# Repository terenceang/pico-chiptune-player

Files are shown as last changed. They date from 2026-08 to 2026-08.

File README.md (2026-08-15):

# Pico Chiptune Player

**Version:** 0.4 (Manufactured Production Release)  
**Author:** Terence Ang <terenceang@mac.com>  
**Company:** MotionFxDesign  
**License:** [CC BY-NC-SA 4.0](LICENSE) (Creative Commons Attribution-NonCommercial-ShareAlike 4.0 International) — **NOT FOR COMMERCIAL USE**  

---

## Overview

The **Pico Chiptune Player** is an open-hardware music player powered by the **Raspberry Pi Pico 2 (RP2350)** microcontroller driving an authentic **General Instrument AY-3-8910** (or **Yamaha YM2149F**) 3-voice Programmable Sound Generator (PSG).

It enables standalone playback of classic AY-3-8910 / YM2149 chiptune music formats (e.g., `.ym`, `.vgm`, `.psg`, `.pt3`) loaded directly from an onboard microSD card, with song and playback metadata displayed on an I2C OLED display.

---

## Hardware Highlights

- **Microcontroller:** Raspberry Pi Pico 2 (RP2350)
- **Sound Generator:** General Instrument AY-3-8910 / Yamaha YM2149F (40-pin DIP)
- **Audio Output:**
  - 3-channel passive summing mixer (`R4`, `R5`, `R7`, `R8` = 1kΩ)
  - Anti-aliasing / low-pass filter capacitor (`C4` = 100nF)
  - AC coupling capacitor (`C3` = 1µF)
  - Onboard Adafruit PAM8302A 2.5W Mono Class-D Audio Amplifier Module (`U3`) with hardware GPIO mute/shutdown control (`SD_Amp` on GPIO9)
  - Direct differential speaker terminals (`OUT+`, `OUT-`)
- **Display:** 0.96" SSD1306 128x64 I2C OLED Display (`U2`)
- **Storage:** MicroSD Card Slot via SPI mode with Card Detect (`J2`)
- **Controls:** 3 tactile pushbuttons (`SW1` Play/Pause, `SW2` Next Track, `SW3` Previous Track)
- **Clock Divider Select:** Solder jumper `JP1` for YM2149 ÷2 internal clock divider selection

---

## Pinout Summary (Raspberry Pi Pico 2)

| GPIO | Pico Pin | Net / Signal | Connected Subsystem |
| :--- | :--- | :--- | :--- |
| **`GPIO0..GPIO7`** | Pins 1, 2, 4..7, 9, 10 | `DA0..DA7` | AY-3-8910 8-Bit Data Bus (Pins 37..30) |
| **`GPIO8`** | Pin 11 | `BC1` | AY-3-8910 Bus Control 1 (Pin 29) |
| **`GPIO9`** | Pin 12 | `SD_Amp` | PAM8302 Audio Amp Shutdown / Mute Control (`U3` Pin 3) |
| **`GPIO10`** | Pin 14 | `BDIR` | AY-3-8910 Bus Direction Control (Pin 27) |
| **`GPIO11`** | Pin 15 | `~RESET` | AY-3-8910 Active-Low Reset (Pin 23) + 10kΩ R3 Pull-down |
| **`GPIO12`** | Pin 16 | `CLOCK` | AY-3-8910 Master Clock Input (Pin 22 via 33Ω series R2) |
| **`GPIO13`** | Pin 17 | `SW_NEXT` | Next Track Button (`SW2`) |
| **`GPIO14`** | Pin 19 | `SW_PLAY` | Play / Pause Button (`SW1`) |
| **`GPIO15`** | Pin 20 | `SW_PREV` | Previous Track Button (`SW3`) |
| **`GPIO16`** | Pin 21 | `OLED_SCL` | 0.96" OLED I2C SCL (`U2` Pin 3) |
| **`GPIO17`** | Pin 22 | `OLED_SDA` | 0.96" OLED I2C SDA (`U2` Pin 4) |
| **`GPIO18`** | Pin 24 | `SD_CS` | MicroSD SPI Chip Select (`J2` Pin 2 + 10kΩ R1 Pull-up) |
| **`GPIO19`** | Pin 25 | `SD_MOSI` | MicroSD SPI Data Input (`J2` Pin 3) |
| **`GPIO20`** | Pin 26 | `SD_SCK` | MicroSD SPI Clock (`J2` Pin 5) |
| **`GPIO21`** | Pin 27 | `SD_MISO` | MicroSD SPI Data Output (`J2` Pin 7) |
| **`GPIO22`** | Pin 29 | `SD_Card_Detect` | MicroSD Card Detect Switch (`J2` Pin 9) |

For the complete hardware design details, circuit topology, and full Bill of Materials with LCSC part numbers, refer to [HARDWARE.md](HARDWARE.md).

---

## License & Commercial Use Notice

Copyright (c) 2026 Terence Ang <terenceang@mac.com> / MotionFxDesign.

This project is licensed under the **Creative Commons Attribution-NonCommercial-ShareAlike 4.0 International License (CC BY-NC-SA 4.0)**.

> **NOT FOR COMMERCIAL USE**  
> This design, including schematics, PCB layouts, Gerber files, firmware, and documentation, is free for personal, hobby, educational, and non-commercial use.  
> **Commercial manufacture, distribution, sale, or bundling for profit is strictly prohibited** without prior written authorization from Terence Ang (<terenceang@mac.com>).

See the [LICENSE](LICENSE) file for the complete license terms.

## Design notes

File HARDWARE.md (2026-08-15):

# Hardware Documentation - Pico Chiptune Player

**Title:** Pico Chiptune Player  
**Author:** Terence Ang <terenceang@mac.com> / MotionFxDesign  
**Company:** MotionFxDesign  
**Status:** Manufactured / Sent to Production (Schematic SSOT)  
**Version / Rev:** 0.4  
**Date:** 2026-08-15  
**License:** Creative Commons Attribution-NonCommercial-ShareAlike 4.0 International (CC BY-NC-SA 4.0) — NOT FOR COMMERCIAL USE  

---

## 1. Overview

The **Pico Chiptune Player** is a dedicated hardware chiptune music player powered by a **Raspberry Pi Pico 2 (RP2350)** microcontroller driving a real **General Instrument AY-3-8910** (or **Yamaha YM2149F**) 3-voice Programmable Sound Generator (PSG).

### Key Features & Subsystems
- **Microcontroller:** Raspberry Pi Pico 2 (RP2350) microcontroller running the chiptune player firmware, file parser, and UI.
- **Sound Generator:** AY-3-8910 / YM2149F 40-pin DIP PSG interfaced via an 8-bit parallel bus (`DA0..DA7`), bus control lines (`BC1`, `BDIR`), active-low reset (`~RESET`), and a hardware master clock output with series damping.
- **Audio Summer & Filter:** 3-channel passive resistive summing network (`R4`, `R5`, `R7` = 1kΩ, `R8` = 1kΩ load) with high-cut low-pass filtering (`C4` = 100nF) and AC output coupling (`C3` = 1µF).
- **Audio Amplifier:** Onboard **Adafruit PAM8302A 2.5W Mono Class-D Audio Amplifier Module** (`U3`) header with hardware GPIO shutdown/mute control (`SD_Amp`).
- **Speaker Output:** Direct differential `OUT+` / `OUT-` speaker terminals on the PAM8302 module breakout.
- **Display:** 0.96" 128x64 I2C OLED display module (`U2`) with bulk and high-frequency decoupling (`C6` = 10µF, `C7` = 100nF).
- **Storage:** Full SPI microSD card socket (`J2`) with hardware card detect (`SD_Card_Detect`) and dedicated pull-up (`R1` = 10kΩ).
- **Navigation Controls:** 3 tactile pushbuttons (`SW1` Play/Pause, `SW2` Next Track, `SW3` Previous Track).
- **Clock Divider Select:** Solder jumper `JP1` to select YM2149 internal ÷2 clock division.

---

## 2. Block Diagram

```
                             +-------------------+
                             |  Raspberry Pi     |
                             | Pico 2 (RP2350)   |
                             +--+---+---+---+----+
                                |   |   |   |
          +---------------------+   |   |   +-----------------------+
          | (SPI: GPIO18..22)       |   | (I2C: GPIO16, 17)         | (GPIO13, 14, 15)
          v                         v   v                           v
+------------------+         +------------+                    +-----------+
| microSD Card     |         | 0.96" OLED |                    | Buttons   |
| Slot (J2)        |         | Display(U2)|                    | (SW1..3)  |
+------------------+         +------------+                    +-----------+
                                    |
            +-----------------------+
            | 8-Bit Parallel Data Bus: DA0..DA7 (GPIO0..7)
            | Bus Control: BC1 (GPIO8), BDIR (GPIO10)
            | Active-Low Reset: ~RESET (GPIO11) + 10kΩ R3 Pull-down
            | Master Clock: CLOCK (GPIO12) + 33Ω R2 Series Damping
            | Amp Shutdown Control: SD_Amp (GPIO9)
            v
  +--------------------+
  | AY-3-8910 / YM2149 | <--- JP1 (YM2149 /SEL ÷2 Clock Mode Jumper)
  +---------+----------+
            |
            | ANALOG_A, ANALOG_B, ANALOG_C
            v
  +--------------------+
  | Passive Mono Mixer | (R4=1k, R5=1k, R7=1k Summing + R8=1k Load + C4=100nF LPF)
  +---------+----------+
            |
            v
  +--------------------+
  | AC Output Coupling | (C3 = 1µF Polarized Electrolytic Cap)
  +---------+----------+
            |
            | Net-(U3-A+)
            v
  +--------------------+
  | Mono Audio Amp     | (U3: Adafruit PAM8302A 2.5W Class-D Module)
  | Breakout Header    | (VIN=+5V with C8=100nF, A-=GND, SD=GPIO9 SD_Amp)
  +---------+----------+
            |
            v
     Differential Speaker Terminals (OUT+ / OUT- on U3)
```

---

## 3. Complete Pinout & Wiring Tables (SSOT)

### 3.1 Raspberry Pi Pico 2 (A1) Pin Connections

| Pico Pin | Pin Name / GPIO | Net Name | Connected To | Signal Description |
| :--- | :--- | :--- | :--- | :--- |
| **Pin 1** | **GPIO0** | `DA0` | AY-3-8910 (U1) Pin 37 | PSG 8-Bit Data Bus Bit 0 |
| **Pin 2** | **GPIO1** | `DA1` | AY-3-8910 (U1) Pin 36 | PSG 8-Bit Data Bus Bit 1 |
| **Pin 3** | **GND** | `GND` | Ground Plane | System Ground |
| **Pin 4** | **GPIO2** | `DA2` | AY-3-8910 (U1) Pin 35 | PSG 8-Bit Data Bus Bit 2 |
| **Pin 5** | **GPIO3** | `DA3` | AY-3-8910 (U1) Pin 34 | PSG 8-Bit Data Bus Bit 3 |
| **Pin 6** | **GPIO4** | `DA4` | AY-3-8910 (U1) Pin 33 | PSG 8-Bit Data Bus Bit 4 |
| **Pin 7** | **GPIO5** | `DA5` | AY-3-8910 (U1) Pin 32 | PSG 8-Bit Data Bus Bit 5 |
| **Pin 8** | **GND** | `GND` | Ground Plane | System Ground |
| **Pin 9** | **GPIO6** | `DA6` | AY-3-8910 (U1) Pin 31 | PSG 8-Bit Data Bus Bit 6 |
| **Pin 10** | **GPIO7** | `DA7` | AY-3-8910 (U1) Pin 30 | PSG 8-Bit Data Bus Bit 7 |
| **Pin 11** | **GPIO8** | `BC1` | AY-3-8910 (U1) Pin 29 | Bus Control 1 (Address Latch / Data Write) |
| **Pin 12** | **GPIO9** | `SD_Amp` | PAM8302 Module (U3) Pin 3 | Audio Amplifier Shutdown Control (Active High Enable / Low Mute) |
| **Pin 13** | **GND** | `GND` | Ground Plane | System Ground |
| **Pin 14** | **GPIO10** | `BDIR` | AY-3-8910 (U1) Pin 27 | Bus Direction Control |
| **Pin 15** | **GPIO11** | `~RESET` | AY-3-8910 (U1) Pin 23, R3 | PSG Active-Low Reset (with 10kΩ pull-down R3 to GND) |
| **Pin 16** | **GPIO12** | `Net-(A1-GPIO12)` | Resistor R2 Pin 2 (33Ω) | PSG Master Clock Output (series damped to U1 Pin 22 `CLOCK`) |
| **Pin 17** | **GPIO13** | `SW_NEXT` | Tact Switch SW2 Pin 1 | Next Track Button (Active Low, Internal Pull-up) |
| **Pin 18** | **GND** | `GND` | Ground Plane | System Ground |
| **Pin 19** | **GPIO14** | `SW_PLAY` | Tact Switch SW1 Pin 1 | Play / Pause Button (Active Low, Internal Pull-up) |
| **Pin 20** | **GPIO15** | `SW_PREV` | Tact Switch SW3 Pin 1 | Previous Track Button (Active Low, Internal Pull-up) |
| **Pin 21** | **GPIO16** | `OLED_SCL` | OLED Display (U2) Pin 3 | I2C Serial Clock (SCL, Internal / Display Pull-up) |
| **Pin 22** | **GPIO17** | `OLED_SDA` | OLED Display (U2) Pin 4 | I2C Serial Data (SDA, Internal / Display Pull-up) |
| **Pin 23** | **GND** | `GND` | Ground Plane | System Ground |
| **Pin 24** | **GPIO18** | `SD_CS` | MicroSD (J2) Pin 2, R1 | SPI Chip Select (CS, with 10kΩ pull-up R1 to +3.3V) |
| **Pin 25** | **GPIO19** | `SD_MOSI` | MicroSD (J2) Pin 3 | SPI Master Out Slave In (CMD / DI) |
| **Pin 26** | **GPIO20** | `SD_SCK` | MicroSD (J2) Pin 5 | SPI Serial Clock (CLK) |
| **Pin 27** | **GPIO21** | `SD_MISO` | MicroSD (J2) Pin 7 | SPI Master In Slave Out (DAT0 / DO) |
| **Pin 28** | **GND** | `GND` | Ground Plane | System Ground |
| **Pin 29** | **GPIO22** | `SD_Card_Detect` | MicroSD (J2) Pin 9 | MicroSD Card Detect (Active Low to GND when inserted) |
| **Pin 30** | **RUN** | `N/C` | — | Reset input (Unconnected) |
| **Pin 31** | **GPIO26_ADC0** | `N/C` | — | Analog input 0 (Unconnected) |
| **Pin 32** | **GPIO27_ADC1** | `N/C` | — | Analog input 1 (Unconnected) |
| **Pin 33** | **AGND** | `N/C` | — | Analog ground (Unconnected) |
| **Pin 34** | **GPIO28_ADC2** | `N/C` | — | Analog input 2 (Unconnected) |
| **Pin 35** | **ADC_VREF** | `N/C` | — | ADC reference (Unconnected) |
| **Pin 36** | **3V3** | `+3.3V` | MicroSD J2, OLED U2, R1, C5..C7 | 3.3V System Power Rail (Sourced from Pico onboard regulator) |
| **Pin 37** | **3V3_EN** | `N/C` | — | 3.3V regulator enable (Unconnected) |
| **Pin 38** | **GND** | `GND` | Ground Plane | System Ground |
| **Pin 39** | **VSYS** | `N/C` | — | System supply input (Unconnected) |
| **Pin 40** | **VBUS** | `+5V` | U1 Pin 40/25/28, U3 Pin 2, C1, C2, C8 | 5V Main Power Rail (Sourced from Pico USB VBUS) |

---

### 3.2 AY-3-8910 / YM2149 Sound Generator (U1) Pinout

| Pin | Symbol | Net Name | Connected To | Notes / Function |
| :--- | :--- | :--- | :--- | :--- |
| **1** | `VSS` | `GND` | Ground Plane | Power Ground |
| **2** | `NC` | `NC` | Unconnected | No Connect |
| **3** | `ANALOG_B` | `ANALOG_B` | Resistor R5 (1kΩ) | Channel B Analog Audio Output |
| **4** | `ANALOG_A` | `ANALOG_A` | Resistor R4 (1kΩ) | Channel A Analog Audio Output |
| **5** | `NC` | `NC` | Unconnected | No Connect |
| **6..13** | `IOB7..IOB0` | `NC` | Unconnected | General Purpose I/O Port B (Unused) |
| **14..21**| `IOA7..IOA0` | `NC` | Unconnected | General Purpose I/O Port A (Unused) |
| **22** | `CLOCK` | `CLOCK` | Resistor R2 Pin 1 (33Ω) | Master Clock Input (Driven from Pico GPIO12 via 33Ω series R2) |
| **23** | `~RESET` | `~RESET` | Pico GPIO11, R3 (10kΩ to GND) | Active-Low Hardware Reset (Boot pull-down holds PSG in reset) |
| **24** | `A9` | `GND` | Ground Plane | Fixed Address Decoding Bit 9 (Tied to GND = 0) |
| **25** | `A8` | `+5V` | +5V Rail | Fixed Address Decoding Bit 8 (Tied to +5V = 1) |
| **26** | `~{CS/Test_2}` | `NET-(JP1-A)` | Solder Jumper JP1 Pin 1 | YM2149 Clock Select (/SEL): Open = 1x Clock; Bridged to GND = ÷2 Clock |
| **27** | `BDIR` | `BDIR` | Pico GPIO10 | Bus Direction Control Line |
| **28** | `BC2` | `+5V` | +5V Rail | Bus Control 2 (Tied permanently HIGH to +5V) |
| **29** | `BC1` | `BC1` | Pico GPIO8 | Bus Control 1 Line |
| **30** | `DA7` | `DA7` | Pico GPIO7 | 8-Bit Bidirectional Data Bus Bit 7 |
| **31** | `DA6` | `DA6` | Pico GPIO6 | 8-Bit Bidirectional Data Bus Bit 6 |
| **32** | `DA5` | `DA5` | Pico GPIO5 | 8-Bit Bidirectional Data Bus Bit 5 |
| **33** | `DA4` | `DA4` | Pico GPIO4 | 8-Bit Bidirectional Data Bus Bit 4 |
| **34** | `DA3` | `DA3` | Pico GPIO3 | 8-Bit Bidirectional Data Bus Bit 3 |
| **35** | `DA2` | `DA2` | Pico GPIO2 | 8-Bit Bidirectional Data Bus Bit 2 |
| **36** | `DA1` | `DA1` | Pico GPIO1 | 8-Bit Bidirectional Data Bus Bit 1 |
| **37** | `DA0` | `DA0` | Pico GPIO0 | 8-Bit Bidirectional Data Bus Bit 0 |
| **38** | `ANALOG_C` | `ANALOG_C` | Resistor R7 (1kΩ) | Channel C Analog Audio Output |
| **39** | `TEST1` | `NC` | Unconnected | Test pin (Unconnected) |
| **40** | `VCC` | `+5V` | +5V Rail | Main +5V Power Supply (Decoupled by C1 10µF bulk + C2 100nF MLCC) |

#### AY-3-8910 Bus State Decoding Table (`BC2` Tied HIGH to +5V)

| `BDIR` (GPIO10) | `BC1` (GPIO8) | Bus State | Operation Description |
| :---: | :---: | :--- | :--- |
| **0** | **0** | **INACTIVE** | PSG data bus is High-Z / Inactive. |
| **0** | **1** | **READ** | Pico reads register contents from PSG data bus `DA[7:0]`. |
| **1** | **0** | **WRITE** | Pico writes data on `DA[7:0]` into currently addressed register. |
| **1** | **1** | **LATCH ADDRESS** | Pico selects target PSG register address (0x00..0x0F) on `DA[7:0]`. |

---

### 3.3 MicroSD Card Socket (J2) Pinout

| Pin | Card Signal | Net Name | Connected To | Description |
| :--- | :--- | :--- | :--- | :--- |
| **1** | `DAT2` | `NC` | Unconnected | Unused in SPI Mode |
| **2** | `DAT3 / CD` | `SD_CS` | Pico GPIO18 (Pin 24), R1 | SPI Chip Select (CS) with 10kΩ pull-up R1 to +3.3V |
| **3** | `CMD` | `SD_MOSI` | Pico GPIO19 (Pin 25) | SPI Data Input (DI / MOSI) |
| **4** | `VDD` | `+3.3V` | +3.3V Rail | +3.3V Power Supply (Decoupled by C5 100nF MLCC) |
| **5** | `CLK` | `SD_SCK` | Pico GPIO20 (Pin 26) | SPI Serial Clock (SCK) |
| **6** | `VSS` | `GND` | Ground Plane | Power Ground |
| **7** | `DAT0` | `SD_MISO` | Pico GPIO21 (Pin 27) | SPI Data Output (DO / MISO) |
| **8** | `DAT1` | `NC` | Unconnected | Unused in SPI Mode |
| **9** | `Card Detect`| `SD_Card_Detect`| Pico GPIO22 (Pin 29) | Card Detect Switch (Shorts to GND when card is inserted) |
| **10** | `Casing` | `GND` | Ground Plane | Metal Shield / Housing Ground |

---

### 3.4 Peripherals: OLED (U2), Audio Amp Module (U3), Buttons (SW1..SW3), Jumper (JP1)

| Designator | Pin / Signal | Net Name | Connected To | Description |
| :--- | :--- | :--- | :--- | :--- |
| **`U2` Pin 1** | `VCC` | `+3.3V` | +3.3V Rail | Display Power (Decoupled by C6 10µF + C7 100nF) |
| **`U2` Pin 2** | `GND` | `GND` | Ground Plane | Display Power Ground |
| **`U2` Pin 3** | `SCL` | `OLED_SCL` | Pico GPIO16 (Pin 21) | I2C Serial Clock Line |
| **`U2` Pin 4** | `SDA` | `OLED_SDA` | Pico GPIO17 (Pin 22) | I2C Serial Data Line |
| **`U3` Pin 1** | `GND` | `GND` | Ground Plane | PAM8302 Power Ground |
| **`U3` Pin 2** | `VIN` | `+5V` | +5V Rail | PAM8302 Power Input (Decoupled by C8 100nF) |
| **`U3` Pin 3** | `SD` | `SD_Amp` | Pico GPIO9 (Pin 12) | Hardware Mute / Shutdown (HIGH = Enable, LOW = Mute) |
| **`U3` Pin 4** | `A-` | `GND` | Ground Plane | Differential Audio Negative Reference Input |
| **`U3` Pin 5** | `A+` | `NET-(U3-A+)` | C3 Pin 2 (Negative lead) | AC-Coupled Audio Input from Mixer Summing Junction |
| **`U3` Pin 6** | `OUT+` | `Net-(U3-OUT+-Pad6)` | Breakout Output Terminal | Positive Differential Class-D Speaker Output |
| **`U3` Pin 7** | `OUT-` | `Net-(U3-OUT--Pad7)` | Breakout Output Terminal | Negative Differential Class-D Speaker Output |
| **`SW1` Pin 1** | `1` | `SW_PLAY` | Pico GPIO14 (Pin 19) | Play / Pause Navigation Button (Internal Pull-Up) |
| **`SW1` Pin 2** | `2` | `GND` | Ground Plane | Ground Return |
| **`SW2` Pin 1** | `1` | `SW_NEXT` | Pico GPIO13 (Pin 17) | Next Track Navigation Button (Internal Pull-Up) |
| **`SW2` Pin 2** | `2` | `GND` | Ground Plane | Ground Return |
| **`SW3` Pin 1** | `1` | `SW_PREV` | Pico GPIO15 (Pin 20) | Previous Track Navigation Button (Internal Pull-Up) |
| **`SW3` Pin 2** | `2` | `GND` | Ground Plane | Ground Return |
| **`JP1` Pin 1** | `A` | `NET-(JP1-A)` | AY-3-8910 (U1) Pin 26 | YM2149 /SEL Clock Divider Select Pin |
| **`JP1` Pin 2** | `B` | `GND` | Ground Plane | Ground Return (Bridge pads to enable ÷2 divider) |

---

### 3.5 Passive Audio Mixer & Filtering Topology

The analog audio outputs from the PSG are combined using a low-noise passive summing junction:

1. **Summing Resistors:**
   - Channel A (U1 Pin 4): `R4` (1kΩ, 0805)
   - Channel B (U1 Pin 3): `R5` (1kΩ, 0805)
   - Channel C (U1 Pin 38): `R7` (1kΩ, 0805)
2. **Summing Node (`Net-(C3-Pad1)`):**
   - **Mixer Load Resistor:** `R8` (1kΩ, 0805) to `GND`. Establishes the passive attenuator baseline impedance and DC ground reference.
   - **Low-Pass Filter Capacitor:** `C4` (100nF, 0805 MLCC) to `GND`. Forms a first-order low-pass filter with the equivalent summing impedance ($R_{eq} \approx 250\,\Omega$, cutoff frequency $f_c \approx 6.3\,\text{kHz}$) to eliminate high-frequency digital clock harmonics and PSG switching noise.
   - **AC Output Coupling Capacitor:** `C3` (1µF, 3x5.4mm Electrolytic). Blocks DC bias from the PSG output pins and passes the audio signal into the PAM8302 `A+` differential audio input (`U3` Pin 5).

---

## 4. Bill of Materials & LCSC Part Mapping (SSOT)

| Designator | Value / Part | Package / Footprint | Quantity | LCSC Part # | Description |
| :--- | :--- | :--- | :---: | :--- | :--- |
| **`A1`** | `RaspberryPi_Pico 2` | `TMCu Module:RPi_Pico_SMD_TH` | 1 | — | Raspberry Pi Pico 2 (RP2350) Microcontroller Module |
| **`C1`** | `10uF` | `Capacitor_SMD:CP_Elec_4x5.4` | 1 | `C3343` | Aluminum Electrolytic Bulk Power Decoupling Cap (U1 +5V) |
| **`C2`** | `100nF` | `Capacitor_SMD:C_0805` | 1 | `C1711` | MLCC 0805 High-Frequency Decoupling Cap (U1 +5V) |
| **`C3`** | `1uF` | `Capacitor_SMD:CP_Elec_3x5.4` | 1 | `C3348` | Aluminum Electrolytic Audio Input AC Coupling Cap |
| **`C4`** | `100nF` | `Capacitor_SMD:C_0805` | 1 | `C1710` | MLCC 0805 Audio Mixer Low-Pass Filter Cap |
| **`C5`** | `100nF` | `Capacitor_SMD:C_0805` | 1 | `C1710` | MLCC 0805 MicroSD +3.3V Decoupling Cap |
| **`C6`** | `10uF` | `Capacitor_SMD:CP_Elec_4x5.4` | 1 | `C3343` | Aluminum Electrolytic Bulk Power Decoupling Cap (U2 +3.3V) |
| **`C7`** | `100nF` | `Capacitor_SMD:C_0805` | 1 | `C1711` | MLCC 0805 High-Frequency Decoupling Cap (U2 +3.3V) |
| **`C8`** | `100nF` | `Capacitor_SMD:C_0805` | 1 | `C1710` | MLCC 0805 PAM8302 +5V Power Decoupling Cap |
| **`J2`** | `MicroSD` | `Terence:MicroSD` | 1 | `C479742` | TF-1115 MicroSD Card Socket (SPI Mode with Card Detect) |
| **`JP1`** | `Clk Div` | `Jumper:SolderJumper-2_P1.3mm_Open` | 1 | — | 2-Pole Solder Jumper (YM2149 /SEL Clock Divider Mode) |
| **`R1`** | `10K` | `Resistor_SMD:R_0805` | 1 | `C17414` | MicroSD SPI `SD_CS` Pull-Up Resistor (+3.3V) |
| **`R2`** | `33` | `Resistor_SMD:R_0805` | 1 | `C17634` | PSG Master Clock (GPIO12) Series Damping Resistor |
| **`R3`** | `10K` | `Resistor_SMD:R_0805` | 1 | `C17414` | AY-3-8910 `~RESET` (GPIO11) Boot Pull-Down Resistor (GND) |
| **`R4`** | `1k` | `Resistor_SMD:R_0805` | 1 | `C17513` | Channel A Audio Mixer Summer Resistor |
| **`R5`** | `1k` | `Resistor_SMD:R_0805` | 1 | `C17513` | Channel B Audio Mixer Summer Resistor |
| **`R7`** | `1k` | `Resistor_SMD:R_0805` | 1 | `C17513` | Channel C Audio Mixer Summer Resistor |
| **`R8`** | `1K` | `Resistor_SMD:R_0805` | 1 | `C17513` | Mixer Summing Junction Load Resistor to GND |
| **`SW1`**| `SW_PUSH_6mm` | `Button_Switch_THT:SW_PUSH_6mm` | 1 | `C17513` | 6x6mm Pushbutton Tactile Switch (Play / Pause, GPIO14) |
| **`SW2`**| `SW_PUSH_6mm` | `Button_Switch_THT:SW_PUSH_6mm` | 1 | `C114217` | 6x6mm Pushbutton Tactile Switch (Next Track, GPIO13) |
| **`SW3`**| `SW_PUSH_6mm` | `Button_Switch_THT:SW_PUSH_6mm` | 1 | `C12740` | 6x6mm Pushbutton Tactile Switch (Previous Track, GPIO15) |
| **`U1`** | `AY-3-8910` | `Package_DIP:DIP-40_W15.24mm` | 1 | — | 3-Voice Programmable Sound Generator IC (DIP-40 Socket) |
| **`U2`** | `0.96"OLED_I2C` | `TModules:OLED 0.96 I2C` | 1 | — | 4-Pin 0.96" SSD1306 I2C OLED Display Module |
| **`U3`** | `PAM8302` | `TModules:PAM8302A_Module` | 1 | — | Adafruit PAM8302A 2.5W Mono Class-D Audio Amplifier Breakout |

---

## 5. Revision History

| Rev | Date | Notes |
| :--- | :--- | :--- |
| **0.4** | **2026-08-15** | **Manufactured Production Release (SSOT)**: Fully aligned documentation with production schematic and manufactured PCB (`Pico_Chiptune_Player_0.4.zip` / `netlist.ipc`). Updated complete Pico GPIO assignments: `CLOCK` on GPIO12 via 33Ω R2, `BDIR` on GPIO10, `~RESET` on GPIO11 with R3 10kΩ pull-down, `BC1` on GPIO8, `SD_Amp` on GPIO9, `SW_PLAY` on GPIO14, `SW_NEXT` on GPIO13, and `SW_PREV` on GPIO15. Documented PAM8302A breakout module header topology (`U3`), 8-capacitor decoupling arrangement (`C1..C8`), and verified all LCSC component part numbers. |
| 0.2 | 2026-08-12 | Intermediate documentation revision. |
| 0.1 | 2026-08-08 | Initial hardware documentation release. |
 
---
 
## 6. License & Non-Commercial Notice
 
Copyright (c) 2026 Terence Ang <terenceang@mac.com> / MotionFxDesign.
 
This hardware project and documentation are licensed under the **Creative Commons Attribution-NonCommercial-ShareAlike 4.0 International License (CC BY-NC-SA 4.0)**.
 
> **NOT FOR COMMERCIAL USE**  
> You are free to share, copy, modify, and build upon this hardware design for personal, hobby, educational, and non-commercial purposes with attribution. Commercial manufacture, sale, or distribution for profit is strictly prohibited without prior written permission from the author.

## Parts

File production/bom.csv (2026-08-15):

Designator | Footprint | Quantity | Value | LCSC Part #
C1, C6 | CP_Elec_4x5.4 | 2 | 10uF | C3343
C2, C7 | 0805 | 2 | 100nF | C1711
C3 | CP_Elec_3x5.4 | 1 | 1uF | C3348
C4, C5, C8 | 0805 | 3 | 100nF | C1710
J2 | MicroSD | 1 | MicroSD | C479742
R1, R3 | 0805 | 2 | 10K | C17414
R2 | 0805 | 1 | 33 | C17634
R4, R5, R7, R8 | 0805 | 4 | 1k | C17513
U2 | OLED 0.96 I2C | 1 | 0.96"OLED_I2C
U3 | PAM8302A_Module | 1 | PAM8302

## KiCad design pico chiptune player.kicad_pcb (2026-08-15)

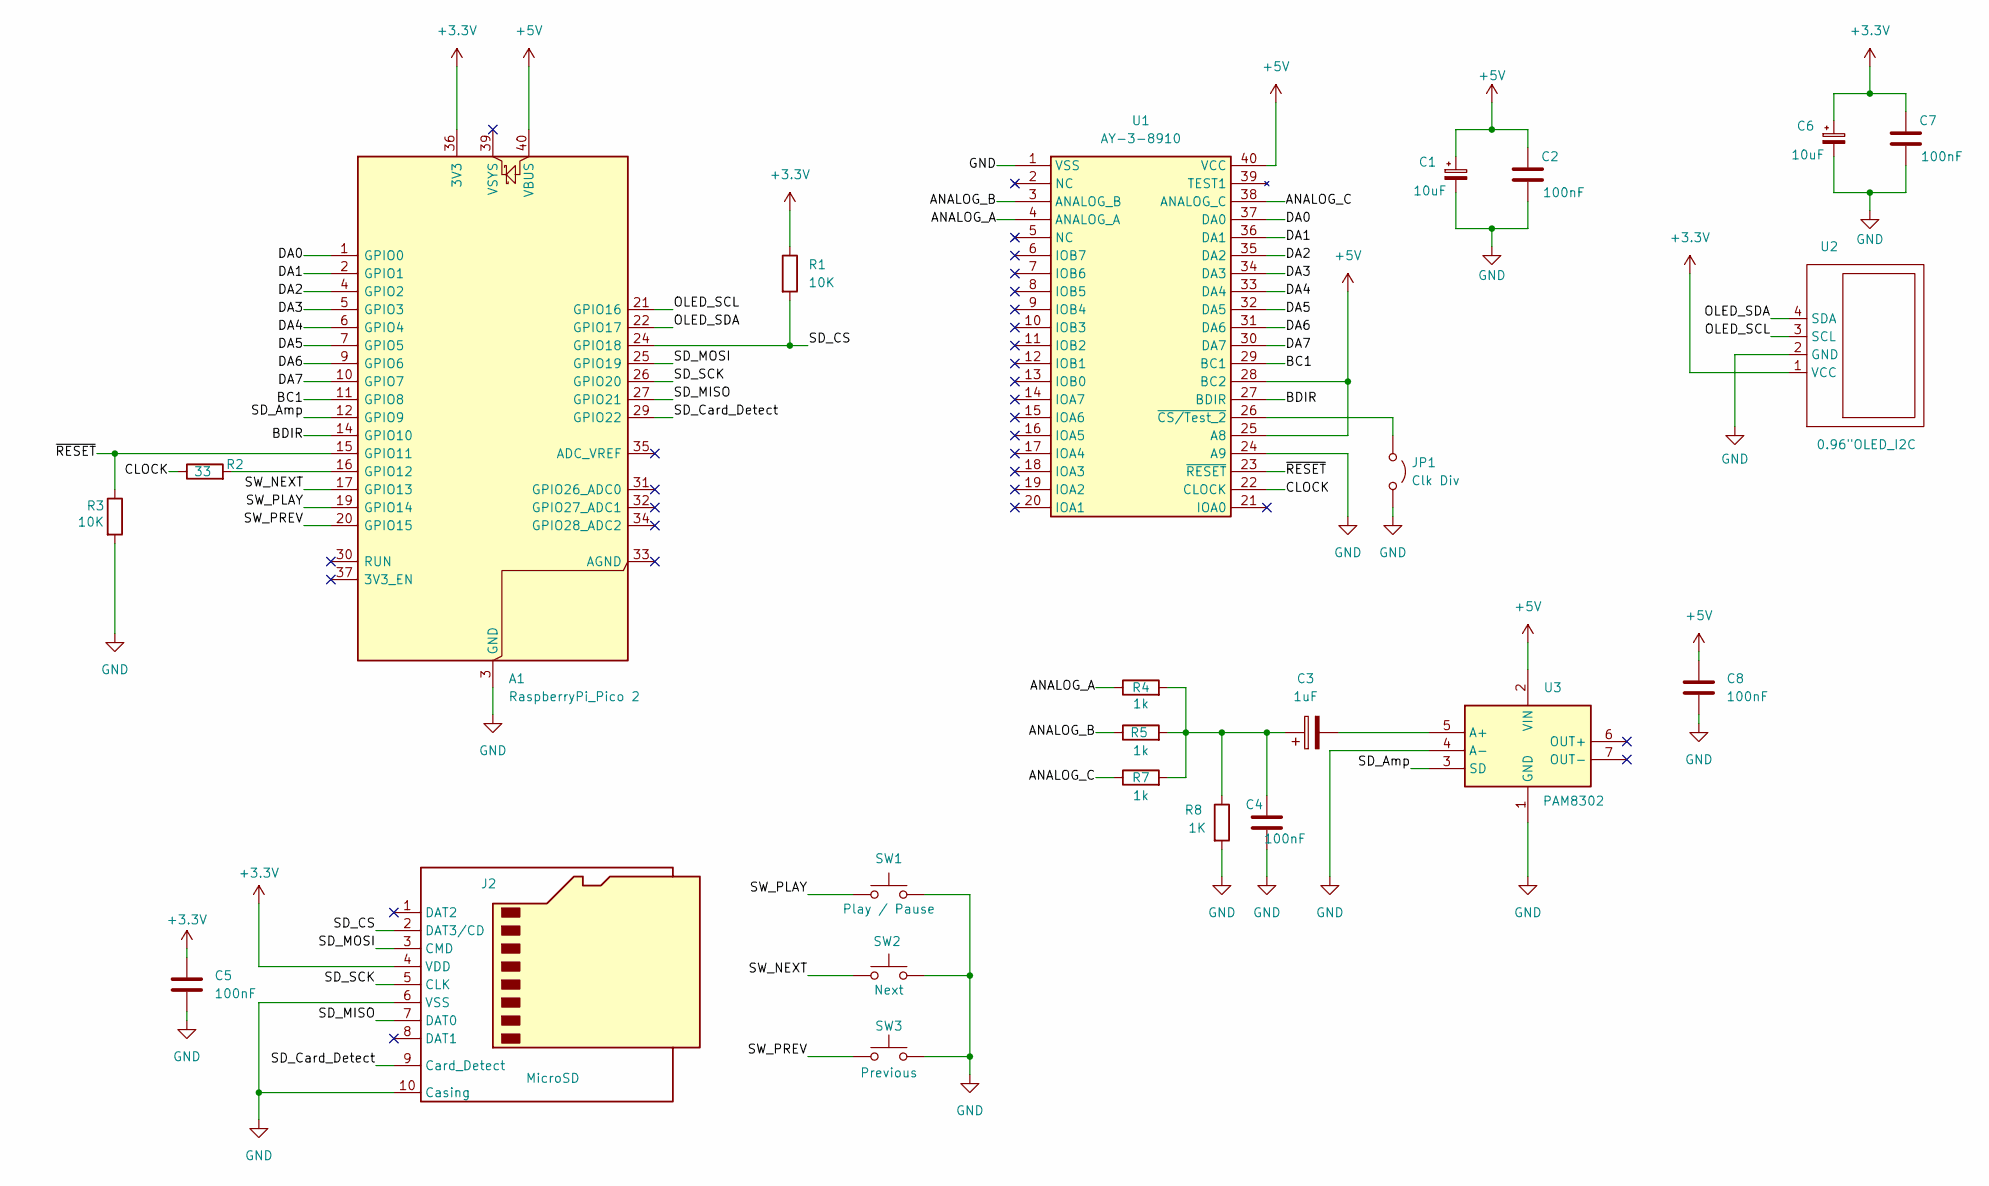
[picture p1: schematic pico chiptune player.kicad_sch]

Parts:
A1: RaspberryPi_Pico 2; RPi_Pico_SMD_TH
C1, C6: 10uF; CP_Elec_4x5.4; LCSC Part # C3343
C2, C7: 100nF; C_0805_2012Metric_Pad1.18x1.45mm_HandSolder; LCSC Part # C1711
C3: 1uF; CP_Elec_3x5.4; LCSC Part # C3348
C4, C5, C8: 100nF; C_0805_2012Metric_Pad1.18x1.45mm_HandSolder; LCSC Part # C1710
J2: MicroSD; LCSC Part # C479742
JP1: Clk Div; SolderJumper-2_P1.3mm_Open_TrianglePad1.0x1.5mm
R1, R3: 10K; R_0805_2012Metric_Pad1.20x1.40mm_HandSolder; LCSC Part # C17414
R2: 33; R_0805_2012Metric_Pad1.20x1.40mm_HandSolder; LCSC Part # C17634
R4, R5, R7: 1k; R_0805_2012Metric_Pad1.20x1.40mm_HandSolder; LCSC Part # C17513
R8: 1K; R_0805_2012Metric_Pad1.20x1.40mm_HandSolder; LCSC Part # C17513
SW1: Play / Pause; SW_PUSH_6mm; LCSC Part # C17513
SW2: Next; SW_PUSH_6mm; LCSC Part # C114217
SW3: Previous; SW_PUSH_6mm; LCSC Part # C12740
U1: AY-3-8910; DIP-40_W15.24mm
U2: 0.96"OLED_I2C; OLED 0.96 I2C
U3: PAM8302; PAM8302A_Module

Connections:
+3.3V: A1.36 (3V3), C5.1, C6.1, C7.1, J2.4 (VDD), R1.1, U2.1 (VCC)
+5V: A1.40 (VBUS), C1.1, C2.1, C8.1, U1.25 (A8), U1.28 (BC2), U1.40 (VCC), U3.2 (VIN)
/ANALOG_A: R4.1, U1.4 (ANALOG_A)
/ANALOG_B: R5.1, U1.3 (ANALOG_B)
/ANALOG_C: R7.1, U1.38 (ANALOG_C)
/BC1: A1.11 (GPIO8), U1.29 (BC1)
/BDIR: A1.14 (GPIO10), U1.27 (BDIR)
/CLOCK: R2.1, U1.22 (CLOCK)
/DA0: A1.1 (GPIO0), U1.37 (DA0)
/DA1: A1.2 (GPIO1), U1.36 (DA1)
/DA2: A1.4 (GPIO2), U1.35 (DA2)
/DA3: A1.5 (GPIO3), U1.34 (DA3)
/DA4: A1.6 (GPIO4), U1.33 (DA4)
/DA5: A1.7 (GPIO5), U1.32 (DA5)
/DA6: A1.9 (GPIO6), U1.31 (DA6)
/DA7: A1.10 (GPIO7), U1.30 (DA7)
/OLED_SCL: A1.21 (GPIO16), U2.3 (SCL)
/OLED_SDA: A1.22 (GPIO17), U2.4 (SDA)
/SD_Amp: A1.12 (GPIO9), U3.3 (SD)
/SD_CS: A1.24 (GPIO18), J2.2 (DAT3/CD), R1.2
/SD_Card_Detect: A1.29 (GPIO22), J2.9 (Card_Detect)
/SD_MISO: A1.27 (GPIO21), J2.7 (DAT0)
/SD_MOSI: A1.25 (GPIO19), J2.3 (CMD)
/SD_SCK: A1.26 (GPIO20), J2.5 (CLK)
/SW_NEXT: A1.17 (GPIO13), SW2.1
/SW_PLAY: A1.19 (GPIO14), SW1.1
/SW_PREV: A1.20 (GPIO15), SW3.1
/~RESET: A1.15 (GPIO11), R3.1, U1.23 (~RESET)
GND: A1.3 (GND), A1.8 (GND), A1.13 (GND), A1.18 (GND), A1.23 (GND), A1.28 (GND), A1.38 (GND), C1.2, C2.2, C4.2, C5.2, C6.2, C7.2, C8.2, J2.6 (VSS), J2.10 (Casing), JP1.2 (B), R3.2, R8.2, SW1.2, SW2.2, SW3.2, U1.1 (VSS), U1.24 (A9), U2.2 (GND), U3.1 (GND), U3.4 (A-)
unnamed: A1.16 (GPIO12), R2.2
unnamed: C3.1, C4.1, R4.2, R5.2, R7.2, R8.1
unnamed: JP1.1 (A), U1.26 (~CS/Test_2)
unnamed: C3.2, U3.5 (A+)

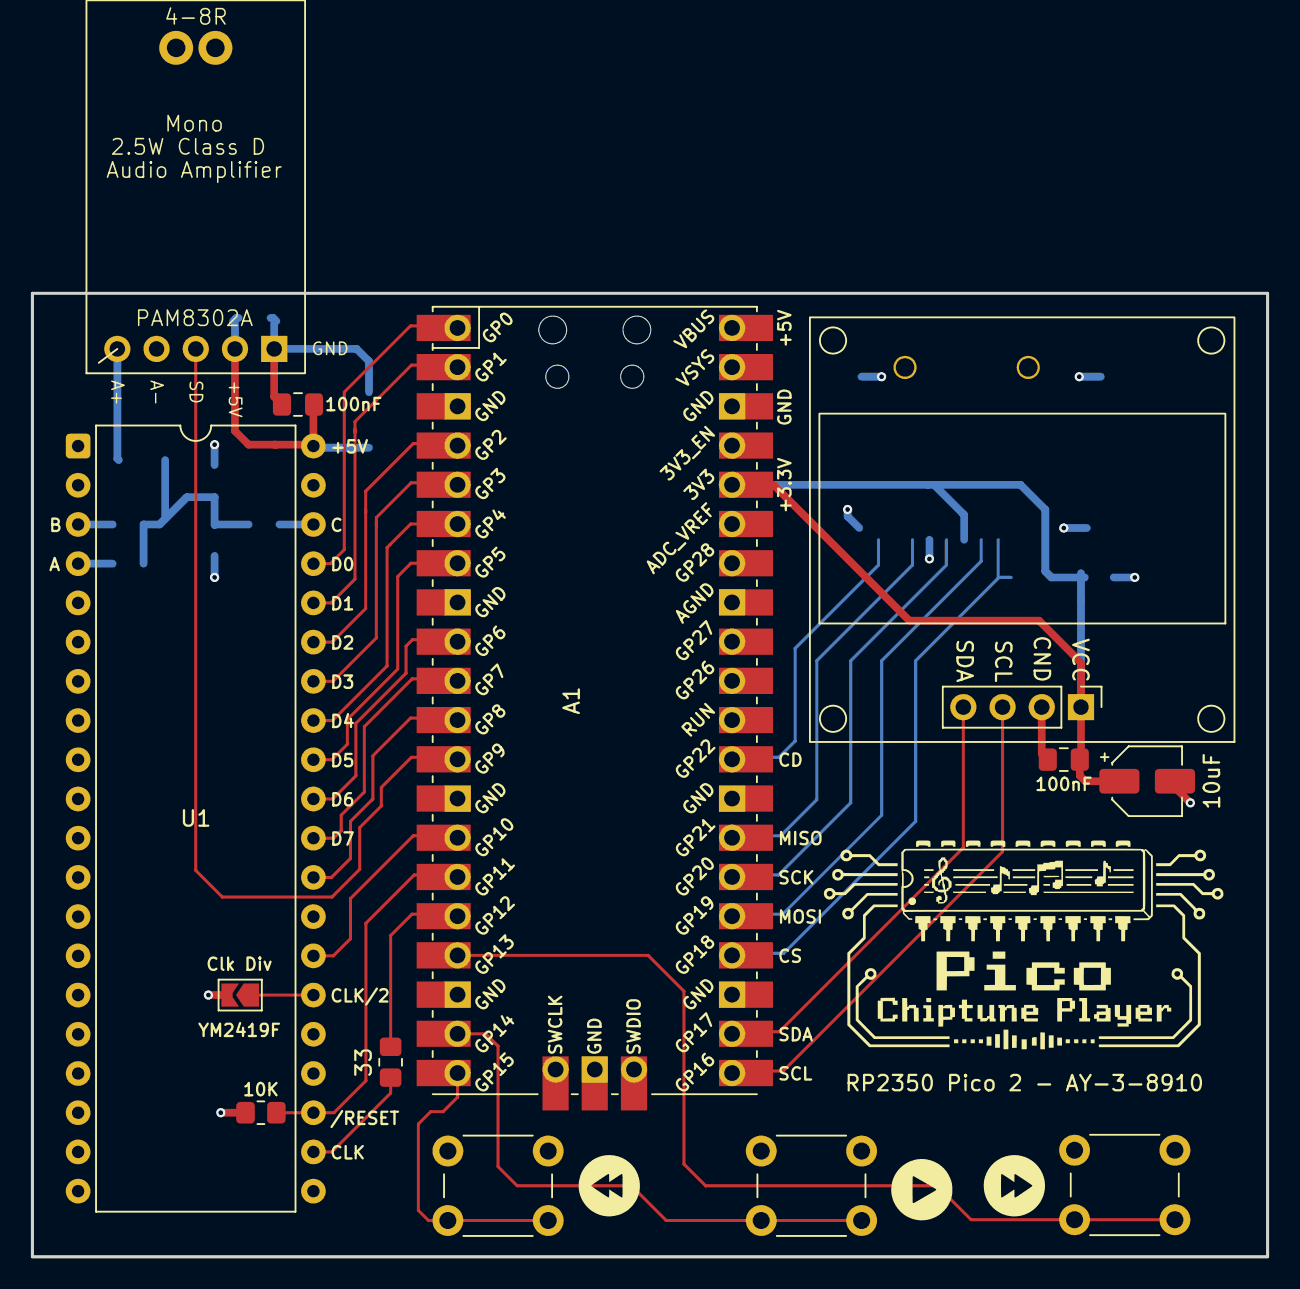
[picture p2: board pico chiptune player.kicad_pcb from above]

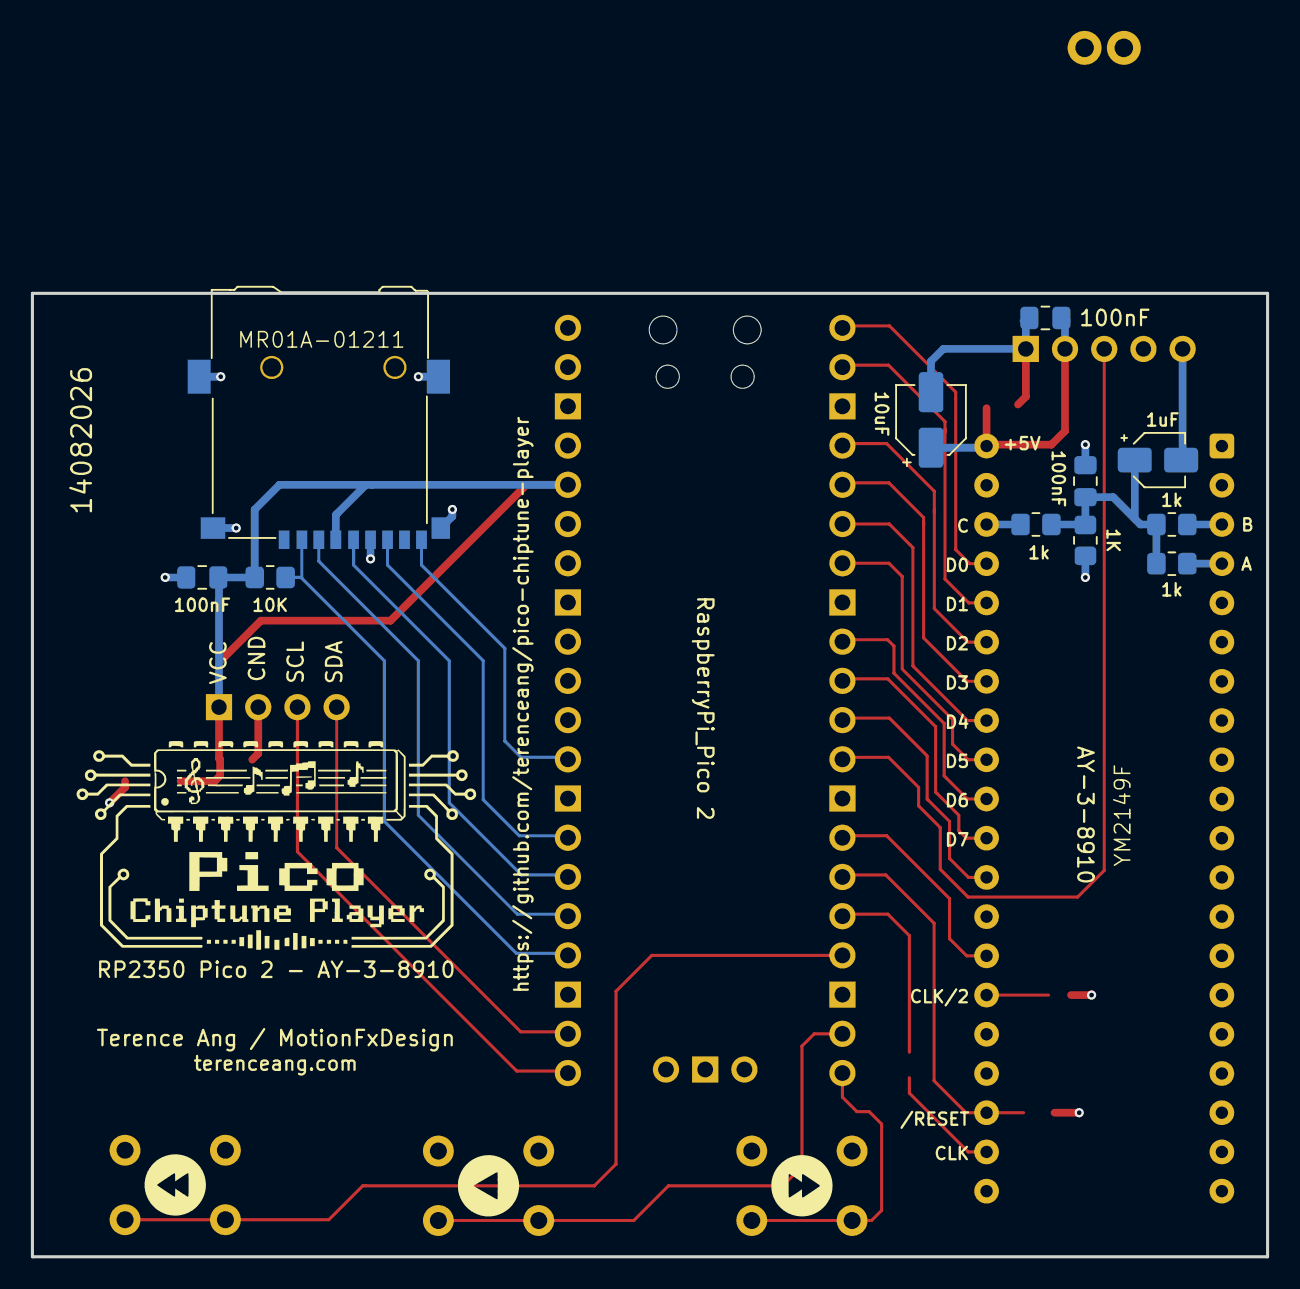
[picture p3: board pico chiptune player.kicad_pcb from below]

Board: 4 copper layers, 80.0 x 62.4 mm, 24 parts (11 on the bottom side), 33 nets.

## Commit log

2026-08-10 Initial commit: Pico Chiptune Player hardware design and documentation
    [bom.csv, designators.csv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]
2026-08-10 Update documentation to include PAM8302A audio amplifier stage
2026-08-10 Add PAM8302A audio amplifier to KiCad schematic and production BOM
    [bom.csv, pico chiptune player.kicad_sch]
2026-08-10 Fix syntax error in schematic file (remove duplicate instances tag)
    [pico chiptune player.kicad_sch]
2026-08-10 Refactor code structure for improved readability and maintainability
    [pico chiptune player.kicad_sch]
2026-08-10 Set hardware revision version to 0.01 across schematic, project settings, and documentation
    [pico chiptune player.kicad_sch]
2026-08-10 Remove unused pico chiptune player.dxf CAD file
    [pico chiptune player.dxf]
2026-08-10 Update .gitignore for DXF files and clean up repository state
    [pico chiptune player-B_Cu.gbr, pico chiptune player-B_Mask.gbr, pico chiptune player-B_Paste.gbr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]
2026-08-11 Refactor schematic and project files: Update active layer, modify visible layers, and add polarized capacitor symbol
    - Changed active layer from 5 to 2 in the KiCad project file.
    - Updated visible layers in the project file for better visibility.
    - Removed unused designators and added a new polarized capacitor symbol in the schematic.
    - Introduced properties for the new capacitor symbol including reference, value, footprint, and description.
    - Cleaned up the schematic by removing the old unpolarized capacitor symbol.
    [pico chiptune player.kicad_pcb, pico chiptune player.kicad_sch]
2026-08-12 docs: update HARDWARE.md and README.md to match schematic
2026-08-12 Update docs for Pico 2 MCU
2026-08-12 Update KiCad version references from 8 to 10 in README
2026-08-12 refactor: remove redundant junctions and update wire connections in schematic
    [pico chiptune player.kicad_sch]
2026-08-12 docs, sch: rev 0.2 — align HARDWARE.md with schematic (SSOT)
    Schematic is the single source of truth; HARDWARE.md updated to match:
    - +5V rail sourced from Pico Pin 40 (VBUS), not Pin 39 (VSYS)
    - Document R8 pull-up on PAM8302 ~SD; correct R3 as SD_CS pull-up
    - PAM8302 pinout re-mapped to KiCad Amplifier_Audio:PAM8302AAS symbol
    - Capacitor types (C3 polarized electrolytic, C4 MLCC ceramic)
    reflect actual schematic footprints
    - Added Revision History section
    Schematic-side changes (by Terence): no_connect markers on unused Pico
    and AY-3-8910 pins, C1 footprint set. Title-block rev bumped 0.1 -> 0.2
    in .kicad_sch and .kicad_pcb; date to 2026-08-12.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
    [pico chiptune player.kicad_pcb, pico chiptune player.kicad_sch]
2026-08-12 prod: regenerate fabrication outputs for rev 0.2
    - Replace Pico_Chiptune_Player_0.1.zip with 0.2.zip
    - Refresh bom.csv, designators.csv, netlist.ipc, positions.csv
    - Rebuild interactive BOM (bom/ibom.html)
    [bom.csv, designators.csv, positions.csv]
2026-08-12 pcb, dru: update silk text sizes to >=0.8mm for DRC compliance and add JLCPCB design rules
    [pico chiptune player.kicad_pcb, pico chiptune player.kicad_sch, positions.csv]
2026-08-12 fix(dru): update JLCPCB custom design rules syntax for KiCad 10 compliance
    [pico chiptune player.kicad_pcb, pico chiptune player.kicad_sch]
2026-08-12 pcb: resolve all text height, thickness, and clearance warnings
    [pico chiptune player.kicad_pcb]
2026-08-12 prod: final manufacturing audit and production package refresh for Rev 0.2
    [bom.csv, pico chiptune player.kicad_pcb, positions.csv]
2026-08-12 sch, bom: add LCSC Part # numbers for JLCPCB SMT PCBA assembly
    [bom.csv, designators.csv, pico chiptune player.kicad_pcb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]
2026-08-12 sch: add LCSC property fields directly to all schematic symbols
    [pico chiptune player.kicad_sch]
2026-08-12 fix: update DNP option in fabrication toolkit and correct netlist references
    [bom.csv, pico chiptune player.kicad_pcb]
2026-08-12 docs: update HARDWARE.md and README.md for Rev 0.2 schematic SSOT
2026-10-10 sch, pcb, docs: update to Rev 0.5 native-compliant SD/OLED pinout
    Remap RP2350 peripherals to their native pins: OLED SDA=GP16/SCL=GP17, SD SCK=GP18/MOSI=GP19/MISO=GP20/CS=GP21 (card detect stays GP22).
    - Schematic: swap OLED SDA/SCL labels, remap SD SPI labels, move R1 pull-up back onto SD_CS; retitle to 0.5
    - PCB: resync A1 pads, reroute the 5 affected nets (0 unconnected), refill zones, retitle to 0.5; DRC unchanged from Rev 0.4
    - Docs: HARDWARE.md/README.md/VERSION set as Rev 0.5 SSOT with errata
2026-10-10 pcb: harden PDN with +3.3V B.Cu pour and power stitching vias
2026-10-11 sch, pcb, docs: dual YM2149 stereo variant (Rev 0.6)
    - Add second PSG (U4) sharing DA0..7/CLOCK/~RESET/BC2, driven by
    dedicated BDIR2 (GPIO26) and BC1_2 (GPIO27) for 6 voices total
    - Add right-channel passive mixer (R9-R12, C9, C10) and second
    PAM8302A amp module (U5) with decoupling (C11-C13) for stereo
    - Widen board to 139.4 x 62.6 mm; autoroute with Freerouting
    (0 unconnected items, ERC 0 errors)
    - Update HARDWARE.md/README.md/VERSION to Rev 0.6
2026-10-11 microSD: switch SPI to 4-bit SDIO (Rev 0.6)
    Re-map microSD socket J2 from SPI to 4-bit SDIO for the RP2350 PIO
    pico_sd_card driver: SD_DAT0..DAT3 -> GPIO18..21, SD_CLK -> GPIO22,
    SD_CMD -> GPIO28. Drop the dedicated card-detect switch (presence now
    detected in software); R1 10k stays on DAT3. Update HARDWARE.md/README.md
    pinout, BOM and revision notes. PCB rerouted: 0 unconnected, 0
    shorts/clearance, 12 cosmetic DRC items; ERC clean.
2026-10-11 pcb: relocate U4/U5 with mirrored passives, resize board, add mounting holes
    Move the right-channel PSG (U4) and amp (U5) parallel on the left beside U1/U3, and mirror R9-R12/C9-C13 to match the U1 channel (position, rotation, copper side).
    Extend zones and reroute the affected SD/PSG signal nets (0 unconnected). Resize the outline to 118x92mm with rounded corners and add four 3mm NPTH corner mounting holes (H1-H4). Update Rev 0.6 docs 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
2026-10-19 sch, pcb, docs: fit YM2149F in both PSG sockets
    U1 was specified as an AY-3-8910 while U4 was a YM2149F. Both share
    CLOCK and the JP1 /SEL net, so bridging JP1 halved the clock on the
    YM2149F only and put the two stereo channels an octave apart. Specify
    both sockets as YM2149F so JP1 divides both chips together; document a
    matched AY-3-8910 pair as an alternative with JP1 open.
    Also relink PCB footprints U4, C9, C11, C12 and R9-R12 to their own
    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
